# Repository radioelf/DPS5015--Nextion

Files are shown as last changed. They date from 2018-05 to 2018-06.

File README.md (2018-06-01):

# Control twod DPS5015 - Nextion 
Codes for the control of two DPS5015 sources through to nextion screen.

Codigos para el control de dos fuentes DPS5015 a través de una pantalla nextion.

https://www.youtube.com/watch?v=COuCyDTJvEc

Creative Commons License Disclaimer

UNLESS OTHERWISE MUTUALLY AGREED TO BY THE PARTIES IN WRITING, LICENSOR OFFERS THE WORK AS-IS AND MAKES NO REPRESENTATIONS OR WARRANTIES OF ANY KIND CONCERNING THE WORK, EXPRESS, IMPLIED, STATUTORY OR OTHERWISE, INCLUDING, WITHOUT LIMITATION, WARRANTIES OF TITLE, MERCHANTIBILITY, FITNESS FOR A PARTICULAR PURPOSE, NONINFRINGEMENT, OR THE ABSENCE OF LATENT OR OTHER DEFECTS, ACCURACY, OR THE PRESENCE OF ABSENCE OF ERRORS, WHETHER OR NOT DISCOVERABLE. SOME JURISDICTIONS DO NOT ALLOW THE EXCLUSION OF IMPLIED WARRANTIES, SO SUCH EXCLUSION MAY NOT APPLY TO YOU. EXCEPT TO THE EXTENT REQUIRED BY APPLICABLE LAW, IN NO EVENT WILL LICENSOR BE LIABLE TO YOU ON ANY LEGAL THEORY FOR ANY SPECIAL, INCIDENTAL, CONSEQUENTIAL, PUNITIVE OR EXEMPLARY DAMAGES ARISING OUT OF THIS LICENSE OR THE USE OF THE WORK, EVEN IF LICENSOR HAS BEEN ADVISED OF THE POSSIBILITY OF SUCH DAMAGES.

http://creativecommons.org/licenses/by-sa/3.0/

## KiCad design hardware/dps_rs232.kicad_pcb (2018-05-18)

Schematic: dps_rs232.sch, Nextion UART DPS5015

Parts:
A1: Arduino_Nano
BZ1: Buzzer; Buzzer_12x9.5RM7.6
C1, C2, C3: 10nF; C_0603_1608Metric
C4: 100nF; C_0603_1608Metric
MK1: +5v; TestPoint_THTPad_D2.0mm_Drill1.0mm
MK2: GND; TestPoint_THTPad_D2.0mm_Drill1.0mm
MK3: A; TestPoint_THTPad_D2.0mm_Drill1.0mm
MK4: RX->nextion; TestPoint_THTPad_D2.0mm_Drill1.0mm
MK5: B; TestPoint_THTPad_D2.0mm_Drill1.0mm
MK6: TX<-nextion; TestPoint_THTPad_D2.0mm_Drill1.0mm
MK7: C; TestPoint_THTPad_D2.0mm_Drill1.0mm
MK8: ON_OFF_encoder; TestPoint_THTPad_D2.0mm_Drill1.0mm
MK9: USB_PC; TestPoint_THTPad_D2.0mm_Drill1.0mm
MK10, MK11: RX; TestPoint_THTPad_D2.0mm_Drill1.0mm
MK12: TX1; TestPoint_THTPad_D2.0mm_Drill1.0mm
MK13: TX2; TestPoint_THTPad_D2.0mm_Drill1.0mm
MK14: ON_3v3-5v; TestPoint_THTPad_D2.0mm_Drill1.0mm
MK15: Led2; TestPoint_THTPad_D2.0mm_Drill1.0mm
MK16: Led1; TestPoint_THTPad_D2.0mm_Drill1.0mm
Q1: Q_PNP; SOT-23
R1, R2, R3, R5, R6: 10K; R_0603_1608Metric
R4, R8, R9: 330R; R_0603_1608Metric
R7: 1K; R_0603_1608Metric
U1: 74HC126; SOIC-14_3.9x8.7mm_P1.27mm

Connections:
+5v: A1.27 (+5V), BZ1.1, C4.2, MK1.1, U1.14
/A: A1.5 (D2), C1.2, R1.1
/B: A1.6 (D3), C2.2, R2.1
/Buzzer: A1.9 (D6), R7.2
/C: A1.7 (D4), C3.2, R3.1
/Ledfuente1: A1.20 (A1), R4.2
/Ledfuente2: A1.8 (D5), R9.2
/ON_3v3-5v: A1.15 (D12), MK14.1
/ON_DPS1: A1.10 (D7), R5.1, U1.1, U1.10
/ON_DPS2: A1.11 (D8), R6.1, U1.4, U1.13
/ON_encoder: A1.12 (D9), MK8.1
/RX1: A1.2 (D0/RX), U1.8, U1.11
/RX2: A1.13 (D10), MK6.1
/TX1: A1.1 (D1/TX), U1.2, U1.5
/TX2: A1.14 (D11), R8.2
/USB_PC: A1.19 (A0), MK9.1
GND: A1.4 (GND), A1.29 (GND), C1.1, C2.1, C3.1, C4.1, MK2.1, Q1.2, R5.2, R6.2, U1.7
unnamed: BZ1.2, Q1.3
unnamed: MK3.1, R1.2
unnamed: MK4.1, R8.1
unnamed: MK5.1, R2.2
unnamed: MK7.1, R3.2
unnamed: MK15.1, R4.1
unnamed: MK16.1, R9.1
unnamed: Q1.1, R7.1
RX->DPS1: MK10.1, U1.3
RX->DPS2: MK11.1, U1.6
TX<-DPS1: MK12.1, U1.9
TX<-DPS2: MK13.1, U1.12

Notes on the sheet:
Encoder
Module: XL7015 DC-DC 5-80V

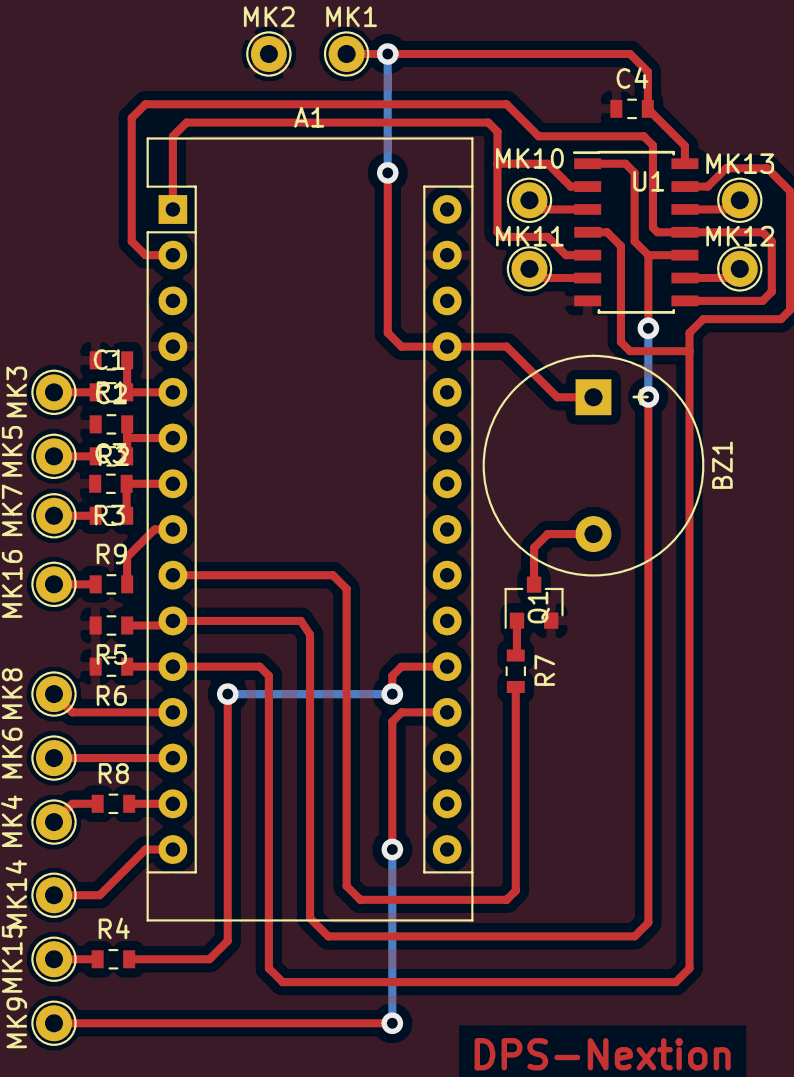
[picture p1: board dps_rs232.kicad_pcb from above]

Board: 2 copper layers, 33 parts (0 on the bottom side), 29 nets.

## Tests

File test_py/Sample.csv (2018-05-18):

time(s) | voltage(V) | current(A)
5 | 0 | 0
5 | 5 | 1
5 | 10 | 2
5 | 15 | 3
5 | 20 | 4
5 | 25 | 5
5 | 30 | 4
5 | 35 | 3
5 | 40 | 2
5 | 45 | 1
10 | 3.3 | 1
10 | 4.75 | 1234
10 | 12.25 | 3456

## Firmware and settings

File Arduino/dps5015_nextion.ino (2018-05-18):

/*
Programa para el control de dos fuentes DPS5015 a traves de pantalla nextion


Mod. ~/.arduino15/packages/arduino/hardware/avr/1.6.21/cores/arduino/HardwareSerial.h
#define SERIAL_RX_BUFFER_SIZE 64
por
#define SERIAL_RX_BUFFER_SIZE 128
Mod. ~/.arduino15/packages/arduino/hardware/avr/1.6.21/libraries/SoftwareSerial/src/SoftwareSerial.h
#define _SS_MAX_RX_BUFF 64
por 
#define _SS_MAX_RX_BUFF 128

configurar nextion 62 61 75 64 73 3d 35 37 36 30 30 ff ff ff  ->bauds=57600ÿÿÿ

*************************************************************************************************
*Creative Commons License Disclaimer

UNLESS OTHERWISE MUTUALLY AGREED TO BY THE PARTIES IN WRITING, LICENSOR OFFERS THE WORK AS-IS
AND MAKES NO REPRESENTATIONS OR WARRANTIES OF ANY KIND CONCERNING THE WORK, EXPRESS, IMPLIED,
STATUTORY OR OTHERWISE, INCLUDING, WITHOUT LIMITATION, WARRANTIES OF TITLE, MERCHANTIBILITY,
FITNESS FOR A PARTICULAR PURPOSE, NONINFRINGEMENT, OR THE ABSENCE OF LATENT OR OTHER DEFECTS,
ACCURACY, OR THE PRESENCE OF ABSENCE OF ERRORS, WHETHER OR NOT DISCOVERABLE. SOME JURISDICTIONS
DO NOT ALLOW THE EXCLUSION OF IMPLIED WARRANTIES, SO SUCH EXCLUSION MAY NOT APPLY TO YOU.
EXCEPT TO THE EXTENT REQUIRED BY APPLICABLE LAW, IN NO EVENT WILL LICENSOR BE LIABLE TO YOU
ON ANY LEGAL THEORY FOR ANY SPECIAL, INCIDENTAL, CONSEQUENTIAL, PUNITIVE OR EXEMPLARY DAMAGES
ARISING OUT OF THIS LICENSE OR THE USE OF THE WORK, EVEN IF LICENSOR HAS BEEN ADVISED OF THE 
POSSIBILITY OF SUCH DAMAGES.

http://creativecommons.org/licenses/by-sa/3.0/

  Author: Radioelf  http://radioelf.blogspot.com.es/

  13-5-18

*/
#include "dps.h"
#include "nextion.h"                                                       
#include <TimerOne.h>
#include <EEPROM.h>

#define ENCODE_A 2
#define ENCODE_B 3
#define PULSADOR_PIN 4                                                      // pin pulsador encoder
#define LED_F1_PIN 5
#define BUZZER_PIN 6                 
//#define ON_DPS1  7                                                        // pin control TX/RX fuente 1 (74HC126)
//#define ON_DPS2  8                                                        // pin control TX/RX fuente 2 (74HC126)
#define ON_encoder  9                                                       // pin habilitación encoder (habilitado->0)
//RX->10 nextion
//TX->11 nextion
#define ON_5_3v3 12
#define LED_PIN 13                                                          // led pcb nano
#define USB_PC_PIN A0                                                       // pin 14 indica selección control por PC A0 (USB)
#define LED_F2_PIN 15

bool pc_control =0;
uint32_t iniTime;

void setup(){
  nextionSerial.begin(57600);                                               // puerto 1 serie nextion a 57600Bps, 128 bytes buffer (Bps máximo para arduino nano)
  Serial.begin(19200);                                                      // puerto 0 serie Modbus a 19200Bps, 128 bytes buffer, 2.0 ms (3.5 character times)
  Serial.setTimeout(2000);                                                  // máximo en milisegundos de espera para la lectura a 2 segundos
  pinMode(10, INPUT);                                                       // pin 10 RX puerto 1
  pinMode(11, OUTPUT);                                                      // pin 11 TX puerto 1
  pinMode(USB_PC_PIN,INPUT);
  pinMode(BUZZER_PIN, OUTPUT);
  pinMode(LED_PIN, OUTPUT);
  pinMode(LED_F1_PIN, OUTPUT);
  pinMode(LED_F2_PIN, OUTPUT);
  pinMode(ON_DPS1, OUTPUT);
  pinMode(ON_DPS2, OUTPUT);
  pinMode(ON_encoder, OUTPUT);
  pinMode(ON_5_3v3, OUTPUT);
  pinMode(PULSADOR_PIN, INPUT_PULLUP);
  pinMode(ENCODE_A, INPUT_PULLUP);
  pinMode(ENCODE_B, INPUT_PULLUP);
  
  digitalWrite(ON_encoder, HIGH);                                           // OFF encoder
  digitalWrite(BUZZER_PIN, LOW);                                            
  digitalWrite(LED_PIN, LOW);
  digitalWrite(LED_F1_PIN, LOW);
  digitalWrite(LED_F2_PIN, LOW);
  digitalWrite(ON_5_3v3, HIGH);
  
  delay (500);                                                                                                       
  ini_nextion();
  if (analogRead(USB_PC_PIN) >500){                                         // comprobamos si tenemos el modo de control por PC
    digitalWrite(ON_5_3v3, LOW);
    txt_nextion("32", "Control  USB");
    cmd_nextion("tsw 255,0");
    dim_nextion();
    digitalWrite(ON_DPS2, LOW);
    digitalWrite(ON_DPS1, LOW);   
    while (analogRead(USB_PC_PIN) >500){
      delay (250);                                                          // esperamos que se pase a control por nextion
    }                                      
    digitalWrite(ON_5_3v3, HIGH);
    selec_esclavo(esclavo);
    reset_nextion();
  }
  if (EEPROM.read(10) !=10){                                                // comprobamos si se programo la eeprom con los valores de defecto
    EEPROM.write(10, 10);                                                   // indicamos programación valores por defecto
    EEPROM.write(0, 1);                                                     // encoder ON
    EEPROM.write(1, 1);                                                     // zumbador ON
    EEPROM.write(2, 5);                                                     // pasos a 5
  }
  if (EEPROM.read(0)){
    EICRA = 0b00001010;                                                     // configuramos flanco de bajada
    EIMSK = 0b00000000;                                                     // interrupciones int0 y int1 des-habilitamos
    pasos_enc =EEPROM.read(2);                                              // obtenemos el número de pasos para el encoder 
    on_off_encoder =1;
    digitalWrite(ON_encoder, LOW);                                          // ON encoder
  }
  if (EEPROM.read(1)){
    Timer1.initialize(100000);                                              // inicializamos a 100ms 
    Timer1.attachInterrupt(buzzer_OFF);                                     // interrupción gestión zumbador                                      
    Timer1.stop();
    on_off_buzzer =1;
  }
  selec_esclavo(1);
  delay (1500);                                                             // esperamos que inicialicen las fuente y la pantalla nextion  
  if (reg_DPS (1, 1, 10, 0)){                                               // ID 1, escribir 1, registro 10, valor 0 (retro iluminación a 0), 01 06 00 0a 00 00 a9 c8
    iniTime = millis();
    do{                                                                     // la espera de la respuesta puede tardar de 200ms a 500ms!!
      RX_serial_DPS(1);                                                     // leemos y NO gestionamos los datos recibidos
      if ((millis() - iniTime) > 750) status_RX_DPS =255;                   // si no hay respuesta n 750 ms salimos (error!)
    }while (status_RX_DPS <2);                                              // esperamos respuesta    
  } 
  if (status_RX_DPS !=255){
    if (reg_DPS (1, 1, 6, 1)){                                              // ID 1, escribir 1, registro 6, valor 1 (bloqueo ON), 01 06 00 06 00 01 a8 0b
      iniTime = millis();
      do{
        RX_serial_DPS(1);                                                   // leemos y NO gestionamos los datos recibidos
        if ((millis() - iniTime) > 750) status_RX_DPS =255;
      }while (status_RX_DPS <2);
    }
  }
  if (status_RX_DPS !=255){   
    if (reg_DPS (1, 0, 6, 0)){                                               // ID 1, leer 0, registro 6, valor 0 (estado bloqueo), 01 03 00 06 00 01 64 0b 
      iniTime = millis();
      do{
        RX_serial_DPS(0);                                                    // leemos y gestionamos los datos recibidos
        if ((millis() - iniTime) > 750) status_RX_DPS =255;
      }while (status_RX_DPS <2);
    }
  }
  // para continuar tenemos que tener el bloqueo teclado de la fuentes a ON->1
  while (datos_RX_DPS[3] !=1 || status_RX_DPS ==255){                         // el valor de la respuesta se encuentra en la posición 3
    digitalWrite(BUZZER_PIN , HIGH);
    digitalWrite(LED_F1_PIN , HIGH);
    delay (500);
    digitalWrite(BUZZER_PIN , LOW);
    digitalWrite(LED_F1_PIN , LOW);
    delay (3000);
  }
  num_nextion("0", 1, 2, 0);                                                  // OK fuente 1 r0.val=1
  
  selec_esclavo(2);
  if (reg_DPS (2, 1, 10, 0)){                                                 // ID 2, escribir 1, registro 10, valor 0 (retro iluminación a 0),02 06 00 0a 00 00 a9 fb
    iniTime = millis();
    do{
      RX_serial_DPS(1);                                                       // leemos y NO gestionamos los datos recibidos
      if ((millis() - iniTime) > 750) status_RX_DPS =255;  

    }while (status_RX_DPS <2);                                            
  }
  if (status_RX_DPS !=255){
    if (reg_DPS (2, 1, 6, 1)){                                                // ID 2, escribir 1, registro 6, valor 1 (bloqueo ON), 02 06 00 06 00 01 a8 38  
      iniTime = millis();
      do{
        RX_serial_DPS(1);                                                     // leemos y NO gestionamos los datos recibidos
        if ((millis() - iniTime) > 750) status_RX_DPS =255;
      }while (status_RX_DPS <2);                                                
    }
  }
  if (status_RX_DPS !=255){
    if (reg_DPS (2, 0, 6, 0)){                                                // ID 2, leer 1, registro 6, valor 0 (estado bloqueo),02 03 00 06 00 01 64 38 
      iniTime = millis();
      do{
        RX_serial_DPS(0);                                                     // leemos y gestionamos los datos recibidos
        if ((millis() - iniTime) > 750) status_RX_DPS =255;                                               
      }while (status_RX_DPS <2);
    }
  }
  // para continuar tenemos que tener el bloqueo teclado a ON->1
  while (datos_RX_DPS[3] !=1 || status_RX_DPS ==255){                         // el valor de la respuesta se encuentra en la posición 3
    digitalWrite(BUZZER_PIN , HIGH);
    digitalWrite(LED_F2_PIN , HIGH);
    delay (150);
    digitalWrite(BUZZER_PIN , LOW);
    digitalWrite(LED_F2_PIN , LOW);
    delay (100);
    digitalWrite(BUZZER_PIN , HIGH);
    digitalWrite(LED_F2_PIN , HIGH);
    delay (150);
    digitalWrite(BUZZER_PIN , LOW);
    digitalWrite(LED_F2_PIN , LOW);
    delay (3000);
  }
  num_nextion("1", 1, 2, 0);                                                  // OK fuente 2 r1.val=1 
  selec_esclavo(1);
}
bool datos_DPS =0, trama_borrada =0, espera_TX_DPS =0, stop_update =0, 
selec_pulsador_tx =0, pausa_test =0, reposo =0;
uint8_t fuente =1, update_dps_1 =0, update_dps_2 =0, fin_reg, esc_test, nextion_Palabras =0;
//******************Principal*************************************************
void loop(){
  switch (pantalla){
    case 0:                                                                   // pantalla principal petición de datos a las fuentes y enviá a la pantalla
      if (ciclo !=0){
        update_pantalla (0, 3);                                               // actualizamos datos U-SET, I-SET, UOUT, IOUT, POUT, UINT, LOCK, PROTECT, CV_CC y ON_OFF  de las fuentes 1 y 2
        update_pantalla (1, 3);                                               // actualizamos datos de memoria S-OVP, S-OCP Y S-OPP  de las fuentes 1 y 2  (-SET, I-SET de la memoria 0 es igual a U-SET, I-SET)  
        if (ciclo ==100){                                                     // arranque 
          nextion_rx(1);                                                      // no aseguramos de iniciar si datos en el buffer de RX de nextion (88 ff ff ff)
        } 
        if (fuente1_run ==1){
          reg_DPS (1, 1, 9, 0);                                               // salida de la fuente fuente 1 parada
          do{
            RX_serial_DPS(1);                                                 // recepción de la respuesta sin gestión
          }while (status_RX_DPS <2); 
          fuente1_run =0;
        }
        buzzer_ON(100000);
        if (fuente2_run ==1){      
          reg_DPS (2, 1, 9, 0);                                               // salida de la fuente fuente 2 parada    
          do{
            RX_serial_DPS(1);                                                 // recepción de la respuesta sin gestión
          }while (status_RX_DPS <2);
          fuente2_run =0;
        }          
        ciclo =0;   
      }   
      data_nextion_RX(0);                                                     // comprobamos si tenemos datos de la pantalla y si tenemos datos los enviamos a la fuente 
      if (pantalla !=0) break;                                                // se tenemos una nueva pagina, salimos
      pulsador();
      if (stop_update ==0) update_pantalla (0, fuente);                       // actualizamos datos U-SET, I-SET, UOUT, IOUT, POUT, UINT, LOCK, PROTECT, CV_CC y ON_OFF  de las fuentes 1 0 2
     
    if (pulsador_encoder ==1) pulsador_selec();                               // si tenemos pulsación
    if (estado_encoder !=0) encoder();                                        // si incrementa->1 o decrementa->2 el encoder
    if (fuente ==1){
      if (selec_pulsador ==6 || selec_pulsador ==30) update_dps_2 =10;        // si tenemos activo el encoder para la fuente 1
      if (fuente1_run ==0 || fuente2_run ==1 || update_dps_2 >9){             // si la fuente 2 esta en marcha o la 1 parada
        fuente =2;
        digitalWrite(LED_PIN, LOW); 
        update_dps_2 =0;
      }else update_dps_2++;
    }else{
      if (selec_pulsador ==1 || selec_pulsador ==20) update_dps_1 =10;        // si tenemos activo el encoder para la fuente 2
      if (fuente2_run ==0 || fuente1_run ==1 || update_dps_1 >9){             // si la fuente 1 esta en marcha o la 2 parada
        fuente =1;
        digitalWrite(LED_PIN, HIGH);
        update_dps_1 =0;
      }else update_dps_1++;
    }
    break;    
    case 1:                                                                   // pantalla opciones
        if (ciclo !=1){
          if (datos_DPS){                                                     // si estábamos esperando datos de la pantalla anterior (principal)
            do{
              RX_serial_DPS(1);                                               // recepción de la respuesta sin gestión
            }while (status_RX_DPS <2);
            datos_DPS =0;
          }
          if (fuente1_run ==1){
            reg_DPS (1, 1, 9, 0);                                             // salida de la fuente fuente 1 parada
            do{
              RX_serial_DPS(1);                                               // recepción de la respuesta sin gestión
            }while (status_RX_DPS <2); 
            fuente1_run =0;
          }
          buzzer_ON(100000);
          if (fuente2_run ==1){      
            reg_DPS (2, 1, 9, 0);                                             // salida de la fuente fuente 2 parada    
            do{
              RX_serial_DPS(1);                                               // recepción de la respuesta sin gestión
            }while (status_RX_DPS <2);
            fuente2_run =0;
          }
          ciclo =1;
      }  
      nextion_rx(0);
      break;     
     case 2:                                                                  // pantalla config
        if (ciclo !=2){
          read_DPS(1, 0x0b, 2);                                               // pedimos datos de la fuente 1, leemos modelo y firmware 0x0b y 0x0c
          do{
            RX_serial_DPS(0);
          }while (status_RX_DPS <2);                                          // esperamos respuesta
          data_nextion_TX(1, 0);                                              // enviamos los datos de la fuente 1 a la pantalla de configuración   
          buzzer_ON(100000);
          read_DPS(2, 0x0b, 2);                                               // pedimos datos de la fuente 2, leemos modelo y firmware 0x0b y 0x0c
          do{
            RX_serial_DPS(0);
          }while (status_RX_DPS <2);                                          // esperamos respuesta
          data_nextion_TX(2, 0);                                              // enviamos los datos del nodo 2 a la pantalla 2 
          ciclo =2;
        }
        nextion_Palabras =nextion_rx(0);                                      // comprobamos si tenemos datos de la pantalla
        if (nextion_Palabras !=0){                                            // si tenemos respuesta de la pantalla
          if (registro ==0xf0){                                               // zumbador
            registro =1;
            on_off_buzzer =datos_TX[1];
            num_nextion("0", on_off_buzzer, 4, 0);                            // c0.val= on/off,  enviamos opción zumbador
          }
          if (registro ==0xf1){                                               // encoder
            selec_pulsador =0;
            registro =0;
            if (datos_TX[1] ==1){
              //EIMSK = 0b00000011;                                           // habilitamos interrupciones int0 y int1
              on_off_encoder =1;
            }else{
              EIMSK = 0b00000000;                                             // des-habilitamos interrupciones int0 y int1    
              on_off_encoder =0;       
            }
            num_nextion("1", on_off_encoder, 4, 0);                           // c1.val= on/off, enviamos opción encoder
          }
          if (registro ==0xf2){                                               // pasos encoder
            registro =2;
            pasos_enc =datos_TX[1];         
          }
          buzzer_ON(100000);
          EEPROM.update(registro, datos_TX[1]); 
        }
      break;     
      case 3:                                                                 // pantalla test - escaneo
        if (ciclo !=3){
          buzzer_ON(100000);
          pausa_test =0;
          esc_test =2;
          ciclo=3;
        }
        nextion_Palabras =nextion_rx(0);
        if (nextion_Palabras !=0){
          if (pantalla !=3) break;
          if (registro ==0x44 || registro ==0x4a){
            (registro ==0x44) ? fin_reg =15: fin_reg =16;                     // registro indicacion fin escaneo voltaje o corriente
            esc_test =0;  
            pausa_test =0;
          }
          if (registro ==0x24){
            for(byte z=1; z <16; z++){                                        // copiamos las palabras recibidas
              datos_TX[15+z] =datos_TX[z];                                    // de la palabra 16 a la 30
            }
            datos_TX[31] =10;                                                 // la ultima palabra indica el número de pasos
            nextion_Palabras = 31;
            fin_reg =14;  
            esc_test =1;
            pausa_test =0;
          }
          if (esc_test <2){
            wire_DPS(esclavo, registro, nextion_Palabras);                    // enviamos a la fuente 1-2 la orden de escaneo o test  
            do{
              RX_serial_DPS(1);                                               // recepción de la respuesta sin gestión
            }while (status_RX_DPS <2);
            do{
              read_DPS(esclavo, 2, 14);                                       // petición de lectura del registro 2 al 15 (leemos 14 registros)
              do{
                RX_serial_DPS(0);                                             // recepción de la respuesta y gestión
              }while (status_RX_DPS <2);
            }while (datos_RX_DPS[fin_reg] ==0);                               // esperamos indicacion en marcha test o escaneo (registro a 1->ON)
            buzzer_ON(200000);
            (esclavo ==1) ? fuente1_run =1: fuente2_run =1;
            digitalWrite(LED_F1_PIN, fuente1_run);
            digitalWrite(LED_F2_PIN, fuente2_run);
            do{
             nextion_Palabras =nextion_rx(0);
              if (nextion_Palabras !=0){
                if (pantalla !=3) break;
                if (registro ==0x4f || registro ==0x43 || registro ==0x49){    // comprobamos si tenemos orden de pausa
                  reg_DPS(esclavo, 1, registro, 1);                            // enviamos pausa
                  do{
                    RX_serial_DPS(1);                                          // recepción de la respuesta sin gestión
                  }while (status_RX_DPS <2);
                  pausa_test =1;
                  break;
                }else
                  pausa_test =0;
              }
              read_DPS(esclavo, 2, 14);                                        // ID, leemos 14 palabras comenzando el el registro 2 
              do{
                RX_serial_DPS(0);                                              // recepción de la respuesta y gestión
              }while (status_RX_DPS <2);
              data_nextion_TX(esclavo, bool (esc_test));                       // enviamos a la pantalla la Uout y Iout
            }while (datos_RX_DPS[fin_reg] ==1);                                // esperamos indicacion de fin test o escaneo
            esc_test =2;
            buzzer_ON(100000);
            (esclavo ==1) ? fuente1_run =0: fuente2_run =0;
            digitalWrite(LED_F1_PIN, fuente1_run);
            digitalWrite(LED_F2_PIN, fuente2_run);
            if (pausa_test ==0)
             num_nextion("0", 1, 0, 0);                                        // enviamos OK va0.val=1
          }
        }
      break;
      case 4:                                                                  // pantalla gráfica fuente 1
        if (ciclo !=4){
          if (fuente1_run ==0){
            reg_DPS (1, 1, 9, 1);                                             // salida de la fuente 1 en marcha
            buzzer_ON(200000);
            do{
              RX_serial_DPS(1);                                               // recepción de la respuesta sin gestión
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

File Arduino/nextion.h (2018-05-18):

/*
 * 
 * https://www.itead.cc/wiki/Nextion_HMI_Solution
 * 
 Nota:
 Todas las instrucciones y parámetros se envían a la pantalla nextion en ascii
 y minúsculas y la instrucción finaliza con tres bytes "0xff 0xff 0xff"
 *
 desde nextion a arduino:
 pagina 0 Principal->245->0xF5 
 pagina 1 opciones ->246->0xF6
 pagina 2 config   ->247->0xF7
 pagina 3 test     ->248->0xF8
 pagina 4 gráfica 1->249->0xF9
 pagina 4 gráfica 2->250->0xFA
 pagina 5 memorias ->251->0xFB
 pagina 6 teclado  ->252->0xFC
 
 Registros:
 0x00 + 1-5 bytes          U-set fuente 1
 0x01 + 1-5 bytes          I-set fuente 1
 0x02 + 1-5 bytes          Uout fuente 1
 0x03 + 1-5 bytes          Iout fuente 1
 0x04 + 1-5 bytes          Wout fuente 1
 0x05 + 1-5 bytes          Uint fuente 1
 0x06 + 1 byte             LOCK fuente 1 (1->bloqueada)
 0x07 + 1 byte             PROTECT fuente 1 (0->OK, 1->OVP, 2->OCP y 3->OPP)
 0x08 + 1 byte             CV/CC fuente 1
 0x09 + 1 byte             fuente 1 ON/OFF (1 on)
 0x0A + 1 byte             fuente 1 retro iluminación (0-4)
 0x0B + 2 byte             modelo fuente 1
 0x0C + 2 byte             versión fuente 1
 0x23 + 1 byte             EXTRACT_M fuente 1 (número de bloque 0-9)
 0x24                      Auto_Test fuente 1 RUN
 0x4F                      Auto_Test fuente 1 pausa       
 0x44                      escaneo tensión fuente 1 RUN
 0x43                      escaneo tensión fuente 1 pausa
 0x4A                      escaneo intensidad fuente 1 RUN
 0x49                      escaneo intensidad fuente 1 pausa                

 0x50-0x57 grupo de memoria 0 fuente 1
 0x60-0x67 grupo de memoria 1 fuente 1
 0x70-0x77 grupo de memoria 2 fuente 1
 0x80-0x87 grupo de memoria 3 fuente 1
 0x90-0x97 grupo de memoria 4 fuente 1
 0xA0-0xA7 grupo de memoria 5 fuente 1
 0xB0-0xB7 grupo de memoria 6 fuente 1
 0xC0-0xC7 grupo de memoria 7 fuente 1
 0xD0-0xD7 grupo de memoria 8 fuente 1
 0xE0-0xE7 grupo de memoria 9 fuente 1
 
 0x10 + 1-5 bytes          U-set fuente 2
 0x11 + 1-5 bytes          I-set fuente 2
 0x12 + 1-5 bytes          Uout fuente 2
 0x13 + 1-5 bytes          Iout fuente 2
 0x14 + 1-5 bytes          Wout fuente 2
 0x15 + 1-5 bytes          Uint fuente 2
 0x16 + 1 byte             LOCK fuente 2 (1->bloqueada)
 0x17 + 1 byte             PROTECT fuente 2 (0->OK, 1->OVP, 2->OCP y 3->OPP)
 0x18 + 1 byte             CV/CC fuente 2
 0x19 + 1 byte             fuente 2 ON/OFF 1 (on)
 0x1A + 1 byte             fuente 2 retro iluminación (0-4)
 0x1B + 2 byte             modelo fuente 2
 0x1C + 2 byte             versión fuente 2
 0x33 + 1 byte             EXTRACT_M fuente 2 (número de bloque 0-9)
 0x34                      Auto_Test fuente 2
 0x4E                      Auto_Test fuente 2 pausa 
 0x45                      escaneo tensión fuente 2
 0x42                      escaneo tensión fuente 2 pausa
 0x4B                      escaneo intensidad fuente 2
 0x48                      escaneo intensidad fuente 2 pausa 
 
 0x58-0x5F grupo de memoria 0 fuente 2
 0x68-0x6F grupo de memoria 1 fuente 2
 0x78-0x7F grupo de memoria 2 fuente 2
 0x88-0x8F grupo de memoria 3 fuente 2
 0x98-0x9F grupo de memoria 4 fuente 2 
 0xA8-0xAF grupo de memoria 5 fuente 2
 0xB8-0xBF grupo de memoria 6 fuente 2
 0xC8-0xCF grupo de memoria 7 fuente 2
 0xD8-0xDF grupo de memoria 8 fuente 2
 0xE8-0xEF grupo de memoria 9 fuente 2
 
Opciones:
 0x0D selección encoder + valor V-set fuente 1
 0x1F selección encoder + estado pulsador bto
 0x20 fin encoder
 0x25 selección encoder + valor V-set fuente 2
 0x2A selección encoder + estado pulsador bt1

 0x40 error en escaneo o test
 0xF0 zumbador on/off
 0xF1 encoder on/off
 0xF2 nº pasos por pulso encoder 
 
 0xFF fin de trama

NO usados:
0x21, 0x22, 0x26, 0x27, 0x28, 0x29, 0x2B, 0x2C, 0x2D, 0x2E,
0x2F, 0x30, 0x31, 0x32, 0x35, 0x36, 0x37, 0x38, 0x39, 0x41,
0x44, 0x46, 0x47, 0x4A, 0x4C, 0x4D, 0xEE, 0XEF, 0XF3, 0XF3,
0XF4, 0XF5, 0XF6, 0XF7, 0XF8, 0XF9, 0XFD, 0XFE. 
 
***********************************************************************************************

Creative Commons License Disclaimer

UNLESS OTHERWISE MUTUALLY AGREED TO BY THE PARTIES IN WRITING, LICENSOR OFFERS THE WORK AS-IS
AND MAKES NO REPRESENTATIONS OR WARRANTIES OF ANY KIND CONCERNING THE WORK, EXPRESS, IMPLIED,
STATUTORY OR OTHERWISE, INCLUDING, WITHOUT LIMITATION, WARRANTIES OF TITLE, MERCHANTIBILITY,
FITNESS FOR A PARTICULAR PURPOSE, NONINFRINGEMENT, OR THE ABSENCE OF LATENT OR OTHER DEFECTS,
ACCURACY, OR THE PRESENCE OF ABSENCE OF ERRORS, WHETHER OR NOT DISCOVERABLE. SOME JURISDICTIONS
DO NOT ALLOW THE EXCLUSION OF IMPLIED WARRANTIES, SO SUCH EXCLUSION MAY NOT APPLY TO YOU.
EXCEPT TO THE EXTENT REQUIRED BY APPLICABLE LAW, IN NO EVENT WILL LICENSOR BE LIABLE TO YOU
ON ANY LEGAL THEORY FOR ANY SPECIAL, INCIDENTAL, CONSEQUENTIAL, PUNITIVE OR EXEMPLARY DAMAGES
ARISING OUT OF THIS LICENSE OR THE USE OF THE WORK, EVEN IF LICENSOR HAS BEEN ADVISED OF THE 
POSSIBILITY OF SUCH DAMAGES.

http://creativecommons.org/licenses/by-sa/3.0/

Author: Radioelf  http://radioelf.blogspot.com.es/
 
 */
#ifndef NEXTION_H
#define NEXTION_H

#include <SoftwareSerial.h>                                                       // https://www.arduino.cc/en/Reference/SoftwareSerial (57600 bps max. arduino nano)

SoftwareSerial nextionSerial(10, 11);                                             // pines para la comunicación serie con la pantalla nextion RX->10, TX->11

bool on_off_buzzer =1, on_off_encoder =1, on_off_run_1 =0, on_off_run_2 =0,
     run1_encoder =0, run2_encoder =0, pulsador_encoder =0, fuente1_run =0, fuente2_run =0;
uint8_t registro=0, pantalla, z, pasos_enc =5, ciclo =100, 
        digito[5]={0}, selec_pulsador =0, grupo_memoria =0x50, byte_rx_nextion[76]={0}; // máximo 76 bytes
volatile uint8_t estado_encoder =0;
int16_t data_encoder =0;

// Pasamos los dígitos recibidos a una palabra int para enviar  a las fuentes
uint16_t dig_palabra(uint8_t digitos){
  switch (digitos){
    case 4:
      return ((digito[1]*1000) + (digito[2]*100) + (digito[3]*10) + (digito[4]));
    case 3:
      return ((digito[1]*100) + (digito[2]*10) + (digito[3]));
    case 2:
      return ((digito[1]*10) + (digito[2]));
    default:
      return (digito[1]);
  }   
}
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
